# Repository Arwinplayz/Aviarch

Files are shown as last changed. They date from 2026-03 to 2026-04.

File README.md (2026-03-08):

# Custom Flight Controller
### Description
This project is a custom rocket flight controller designed in KiCad for Thrust Vector Control (TVC) Rockets. The board is responsible for controlling servos that adjust the rocket's thrust direction, allowing the rocket to stabilise and guide itself during flight.

### How to Use the Project
The flight controller is designed to be manufactured from the provided PCB files and assembled with the required components. Once assembled, firmware can be uploaded to the microcontroller. The board can then be added into a rocket system where it processes flight data in real time and adjusts the thrust vector to stabilise and guide the rocket.

### Why I Made the Project
I created this project to learn more about electronics, PCB design, and TVC. Designing a flight controller provided me with new experience on hardware design, control systems, and how to use kicad properly.
The goal was to build a controller specifically suited for TVC rockets allowing me to understand how rocket control systems work.

---

## Screenshots

### 1. Overall
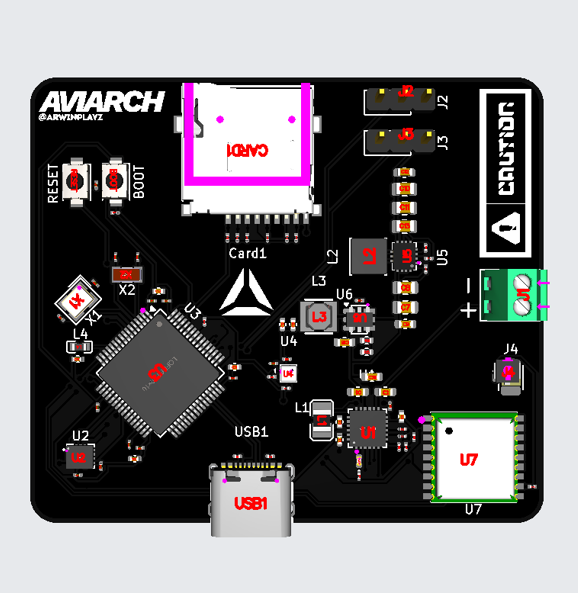
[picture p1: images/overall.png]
Flight Controller Screenshot
  

### 2. Schematic
Schematic Screenshot  

### 3. PCB layout
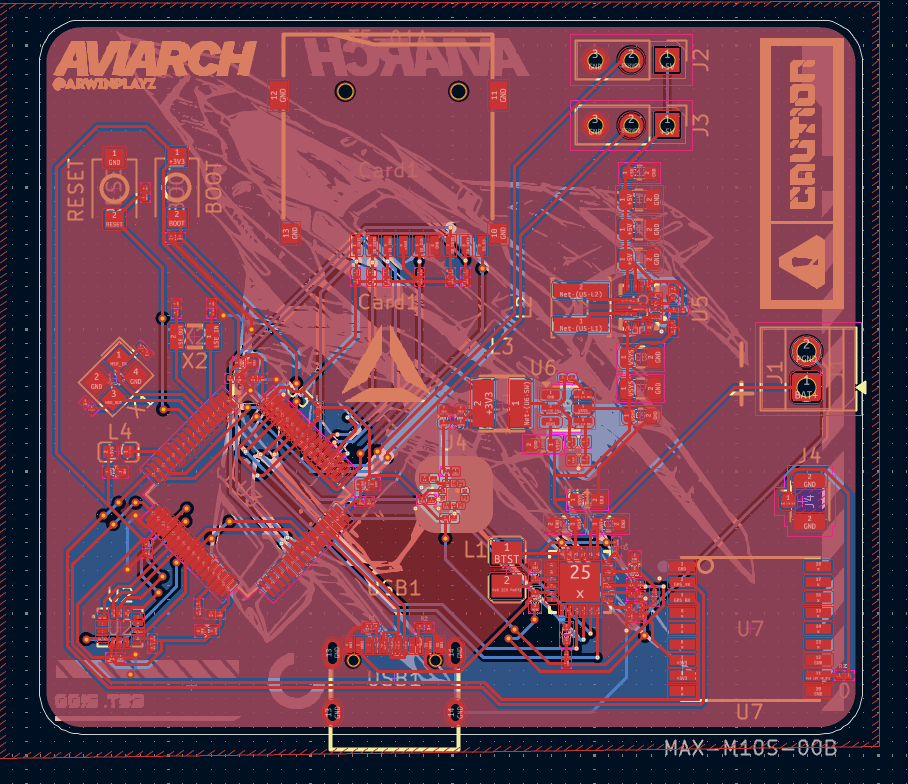
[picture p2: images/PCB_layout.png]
PCB Screenshot
  

### 4. Design
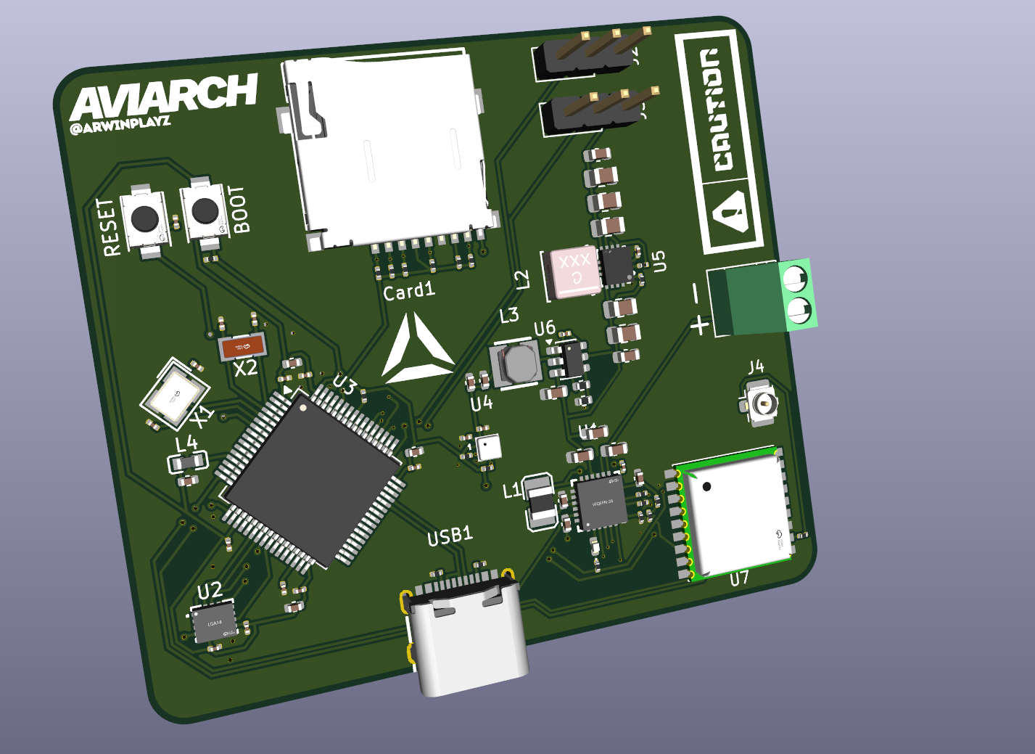
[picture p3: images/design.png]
Design Screenshot


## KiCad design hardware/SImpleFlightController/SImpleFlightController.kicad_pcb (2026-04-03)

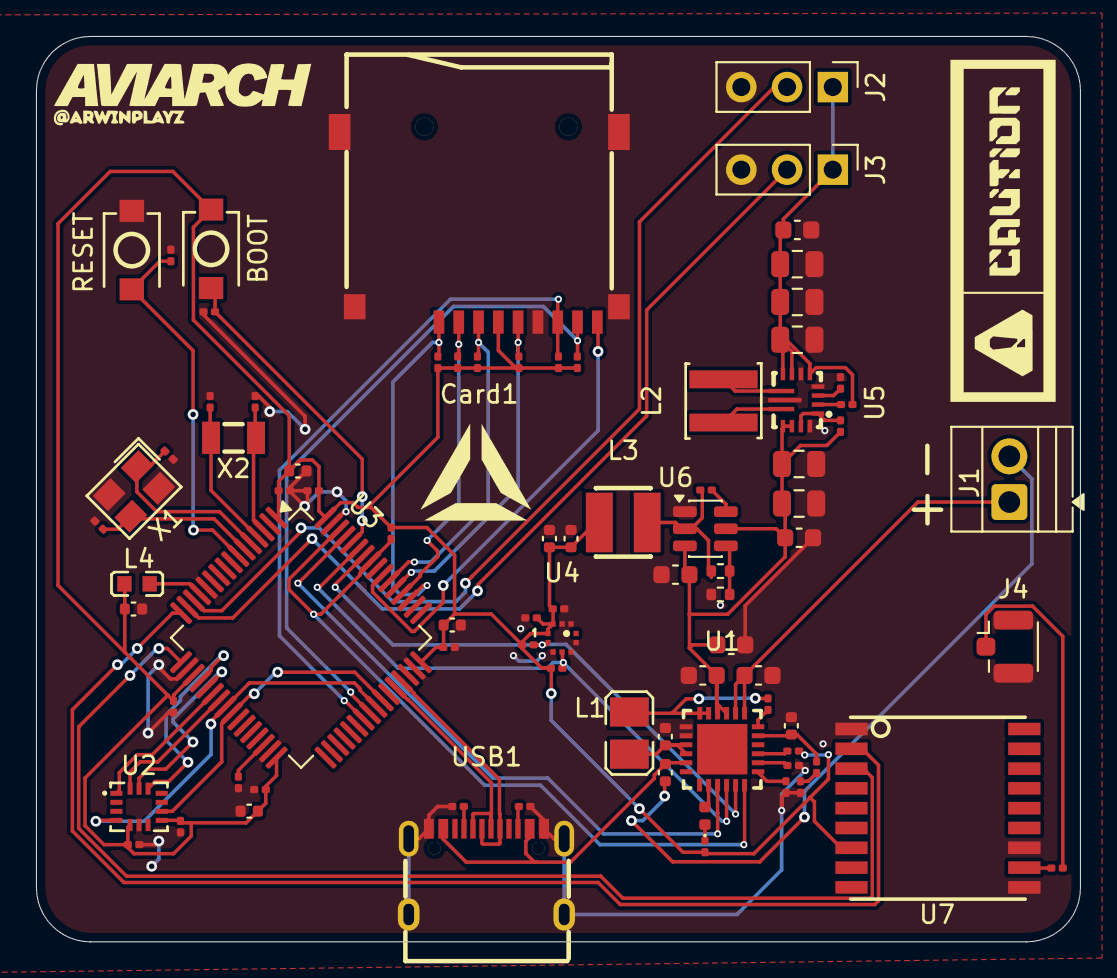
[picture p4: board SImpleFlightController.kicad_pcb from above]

Board: 2 copper layers, 58.0 x 50.3 mm, 83 parts (0 on the bottom side), 60 nets.

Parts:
BOOT: TS-1088-AR02016; SW-SMD_L3.9-W3.0-P4.45
C1, C28, C29, C30: 1uF; C_0402_1005Metric
C2, C9, C12: 10uF; C_0603_1608Metric
C3, C5, C31: 10uF; C_0402_1005Metric
C4: 47nF; C_0201_0603Metric
C6, C38: 22uF; C_0603_1608Metric
C7, C8: 10uF; C_0805_2012Metric
C10, C11, C13: 22uF; C_0805_2012Metric
C14: 100uF; C_0201_0603Metric
C15, C19, C20, C21, C22, C23, C24, C25, C26, C27, C37: 100nF; C_0201_0603Metric
C16: 2.2uF; C_0603_1608Metric
C17, C18: 22uF; C_0402_1005Metric
C32: 2.2uF; C_0201_0603Metric
C33, C34: 20pF; C_0201_0603Metric
C35, C36: 6.8pF; C_0201_0603Metric
Card1: TF-01A; TF-SMD_TF-01A
D1: LED; LED_0402_1005Metric
J1: Screw_Terminal_01x02; TerminalBlock_Xinya_XY308-2.54-2P_1x02_P2.54mm_Horizontal
J2, J3: Conn_01x03; PinHeader_1x03_P2.54mm_Vertical
J4: Conn_Coaxial; U.FL_Hirose_U.FL-R-SMT-1_Vertical
L1: 1uH; L2520
L2: 1.5uH; IND-SMD_L4.0-W4.0-A
L3: 5.6uH; IND-SMD_L3.0-W3.0
L4: FCM1608KF-601T03; L0603
R1, R2: 5.1K; R_0201_0603Metric
R3: 383; R_0201_0603Metric
R4: 5.23K; R_0201_0603Metric
R5: 30.1K; R_0201_0603Metric
R6, R7, R8, R9, R10, R11, R12, R13, R16, R17, R18, R19, R20, R21, R22: 10K; R_0201_0603Metric
R14: 100K; R_0402_1005Metric
R15: 22.1K; R_0402_1005Metric
R23: 0; R_0201_0603Metric
RESET: TS-1088-AR02016; SW-SMD_L3.9-W3.0-P4.45
U1: BQ25883RGER; VFQFPN-24_L4.0-W4.0-P0.50-BL-EP2.8
U2: ICM-45686; LGA-14_L3.0-W2.5-P0.50-TL
U3: STM32F722RETx; LQFP-64_10x10mm_P0.5mm
U4: BMP580; LGA-10_L2.0-W2.0-P0.50-TL_BMP580
U5: TPS63070RNMR; VQFN-HR-15_L3.0-W2.5-P0.50-BL_TPS63070RNMR
U6: LMR51430; SOT-23-6
U7: MAX-M10S-00B; SMD-18_L10.1-W9.7-P1.10-TL_SKG09F
USB1: TYPE-C 16PIN 2MD(073); USB-C-SMD_TYPE-C-6PIN-2MD-073
X1: X322525MOB4SI; CRYSTAL-SMD_4P-L3.2-W2.5-BL
X2: Q13FC1350000400; FC-135R_L3.2-W1.5

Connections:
+3V3: BOOT.1, C17.1, C18.1, C19.1, C20.1, C21.1, C22.1, C23.1, C24.1, C25.1, C26.1, C27.1, C28.1, C29.1, C30.1, C31.1, Card1.4 (VDD), L3.2, L4.2, R7.2, R8.2, R9.2, R10.2, R11.2, R16.2, R17.2, R18.2, R19.2, R20.2, R21.2, U2.5 (VDDIO), U2.8 (VDD), U3.1 (VBAT), U3.19 (VDD), U3.32 (VDD), U3.48 (VDD), U3.64 (VDD), U4.1 (VDDIO), U4.10 (VDD), U7.7 (V_IO), U7.8 (VCC)
+5V: C10.1, C11.1, C12.1, C13.1, J2.1, J3.1, R13.1, U5.5 (FB), U5.7 (Vout), U5.8 (Vout)
/BOOT: BOOT.2, R22.2, U3.60 (BOOT0)
/BQ_CE: U1.3 (~CE), U3.61 (PB8)
/BQ_INT: R11.1, U1.6 (~INT), U3.57 (PB5), U3.62 (PB9)
/BQ_PG: R8.1, U1.9 (~PG)
/BTST: C4.1, L1.1, U1.17 (SW), U1.18 (SW)
/GPS_RX: U3.17 (PA3), U7.3 (RXD)
/GPS_TX: U3.16 (PA2), U7.2 (TXD)
/HSE_IN: C33.1, U3.5 (PH0), X1.1 (OSC1)
/HSE_OUT: C34.1, U3.6 (PH1), X1.3 (OSC2)
/I2C_SCL: R10.1, U1.5 (SCL), U3.58 (PB6), U4.2 (SCK)
/I2C_SDA: R9.1, U1.4 (SDA), U3.59 (PB7), U4.4 (SDI)
/ICM_CS: U2.12 (AP_CS), U3.20 (PA4)
/ICM_INT1: U2.4 (INT1/INT), U3.24 (PC4), U3.41 (PA8)
/ICM_INT2: U2.9 (INT2/FSYNC/CLKIN), U3.25 (PB0), U3.42 (PA9)
/ICM_SCK: U2.13 (AP_SCL/AP_SCLK), U3.21 (PA5)
/ICM_SDI: U2.14 (AP_SDA/AP_SDIO/AP_SDI), U3.23 (PA7)
/ICM_SDO: U2.1 (AP_SDO/AP_AD0), U3.22 (PA6)
/LSE_IN: C35.1, U3.3 (PC14), X2.1
/LSE_OUT: C36.1, U3.4 (PC15), X2.2
/RESET: C37.2, RESET.2, U3.7 (NRST)
/SD_CD: Card1.9 (CD), U3.55 (PB3)
/SD_CLK: Card1.5 (CLK(SCLK)), R21.1, U3.53 (PC12)
/SD_CMD: Card1.3 (CMD(DI)), R20.1, U3.54 (PD2)
/SD_DAT0: Card1.7 (DAT0(D0)), R16.1, U3.39 (PC8)
/SD_DAT1: Card1.8 (DAT1(RSV)), R17.1, U3.40 (PC9)
/SD_DAT2: Card1.1 (DAT2(RSV)), R18.1, U3.51 (PC10)
/SD_DAT3: Card1.2 (CDDAT3(CS)), R19.1, U3.52 (PC11)
/SERVO1: J2.2, U3.14 (PA0)
/SERVO2: J3.2, U3.15 (PA1)
/USB_DN: U3.44 (PA11), USB1.5 (DN2), USB1.7 (DN1)
/USB_DP: U3.45 (PA12), USB1.6 (DP1), USB1.8 (DP2)
BAT+: C2.1, J1.1, U1.13 (BAT), U1.14 (BAT)
GND: C2.2, C3.2, C5.2, C6.2, C7.2, C8.2, C9.2, C10.2, C11.2, C12.2, C13.2, C14.1, C16.2, C17.2, C18.2, C19.2, C20.2, C21.2, C22.2, C23.2, C24.2, C25.2, C26.2, C27.2, C28.2, C29.2, C30.2, C31.2, C32.2, C33.2, C34.2, C35.2, C36.2, C37.1, C38.2, Card1.6 (VSS), Card1.10 (GND), Card1.11 (GND), Card1.12 (GND), Card1.13 (GND), J2.3, J3.3, J4.2 (Ext), R1.1, R2.1, R3.1, R5.1, R6.1, R15.1, R22.1, RESET.1, U1.19 (GND), U1.20 (GND), U2.6 (GND), U3.12 (VSSA), U3.18 (VSS), U3.31 (VSS), U3.47 (VSS), U3.63 (VSS), U4.3 (VSS), U4.5 (SDO), U4.6 (CSB), U4.8 (VSS), U4.9 (VSS), U5.4 (GND), U5.6 (FB2), U5.10 (PGND), U5.15 (Vsel), U6.1 (GND), U7.1 (GND), U7.10 (GND), U7.12 (GND), USB1.1 (GND), USB1.12 (GND), USB1.13 (SHELL), USB1.14 (SHELL), X1.2 (GND), X1.4 (GND)
unnamed: C5.1, L1.2, U1.21 (PMID), U1.22 (PMID)
unnamed: D1.2 (A), U1.2 (STAT)
unnamed: D1.1 (K), R7.1
unnamed: J4.1 (In), R23.2
unnamed: R4.1, R5.2
unnamed: C4.2, U1.12 (BTST)
unnamed: R3.2, U1.8 (ILIM)
unnamed: R6.2, U1.7 (TS)
unnamed: C32.1, U3.30 (VCAP_1)
unnamed: L4.1, U3.13 (VDDA)
unnamed: R12.2, U5.1 (PS/SYNC), U5.14 (EN)
unnamed: L2.1, U5.11 (L1)
unnamed: L2.2, U5.9 (L2)
unnamed: R13.2, U5.2 (PG)
unnamed: C14.2, U5.3 (Vaux)
unnamed: C15.1, U6.6 (CB)
unnamed: R14.1, R15.2, U6.4 (FB)
unnamed: C15.2, L3.1, R14.2, U6.2 (SW)
unnamed: R23.1, U7.11 (RF_IN)
unnamed: R1.2, USB1.4 (CC1)
unnamed: R2.2, USB1.10 (CC2)
PGND: C1.2, J1.2
VBUS: C1.1, U1.23 (VBUS), USB1.2 (VBUS), USB1.11 (VBUS)
VREGN: C3.1, R4.2, U1.11 (REGN)
VSYS: C6.1, C7.1, C8.1, C9.1, C16.1, C38.1, R12.1, U1.15 (SYS), U1.16 (SYS), U5.12 (Vin), U5.13 (Vin), U6.3 (VIN), U6.5 (EN)
